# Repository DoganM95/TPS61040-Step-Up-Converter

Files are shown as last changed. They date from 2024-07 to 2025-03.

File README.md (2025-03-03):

# Intro

Step-Up converter module using TPS61040, ideal to boost a single li-ion cell (typically 2.5V - 4.2V) or a USB power supply (5V) to up to 28V, to power any device that does not need lots of current, but requires a very low quiescent current to ensure the battery is not drained, when there is no load.

## Specs of the IC

- 1.8V - 6V input
- 1.8V - 28V adj. output Voltage
- 0.4A output current
- 28uA quiescent current

## Specs of the PCB (measured)

- 2.2V - 6V input
- 2.2V - 28V adj. output
- 0.4A output
- 60 uA quiescent current

## Power Consumption 

Power consumed by the board alone with no load (quiescent current)

- 61 uA @ 6.0V in (6V out)
- 59 uA @ 5.0V in (6V out)
- 60 uA @ 4.2V in (6V out)
- 63 uA @ 3.3V in (6V out)
- 65 uA @ 3.0V in (6V out)
- 73 uA @ 2.2V in (6V out)

## Power Output

output range 2.93V - 13.87V  
output power @ 3.0V in  
V out without load -> V out with load after @  

- 13.87V loadless -> 13.8V @ 100mA  
- 12.00V loadless -> 11.8V @ 100 mA  
- 9.00V loadless -> 8.8V @ 100 mA  
- 6.0V loadless -> 5.8V @ 100mA  
- 5.0V loadless -> 4.7V @ 100mA  
- 3.3V loadless -> 3.0V @ 100mA  

## BOM

- `C_FF`: 0603 22pF
- `C_IN`: 0603 4.7uF
- `C_O`: 0603 1nF
- `D1`: any Schottky between SS14 & SS54
- `EN_J`: short, if board should be always on -> EN becomes redundant
- `L1`: CD43 10uH
- `R1`: 0603 up to 1MOhm, use if VR1 is unnecessary and needed resstance is known
- `R2`: 0603 100kOhm
- `U1`: SOT23-5 TPS61040
- `VR1`: 3x3 trimpot 1MOhm, sets output voltage by adjusting its resistance

## PCB

<table>
  <tr>
    <td>
      PCB Top View
    </td>
    <td>
      PCB Bottom View
    </td>
  </tr>
</table>

## Schematic



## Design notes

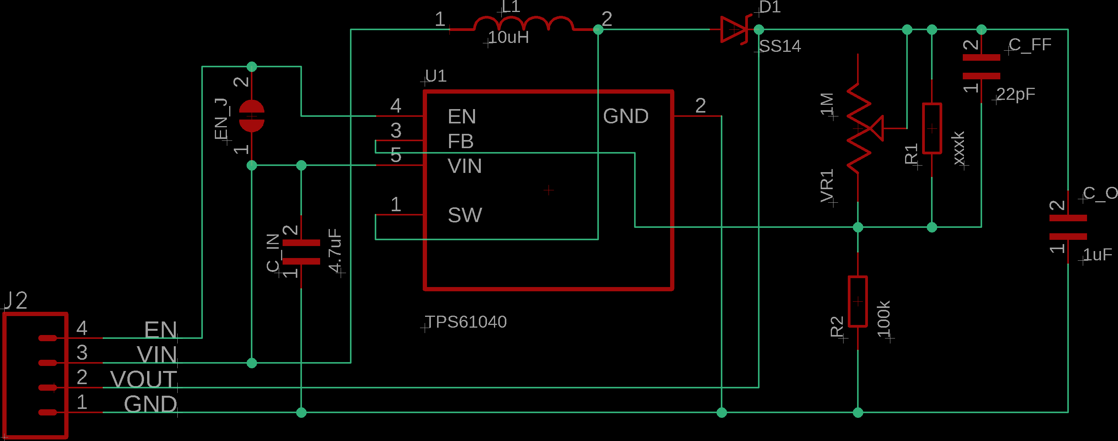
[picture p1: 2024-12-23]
assets/1.2_schematic.png

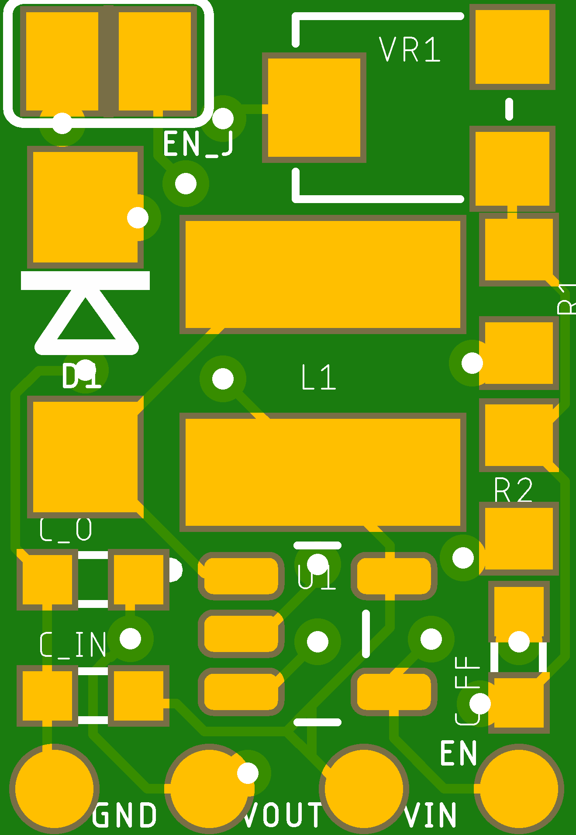
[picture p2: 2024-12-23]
assets/1.1-top.png

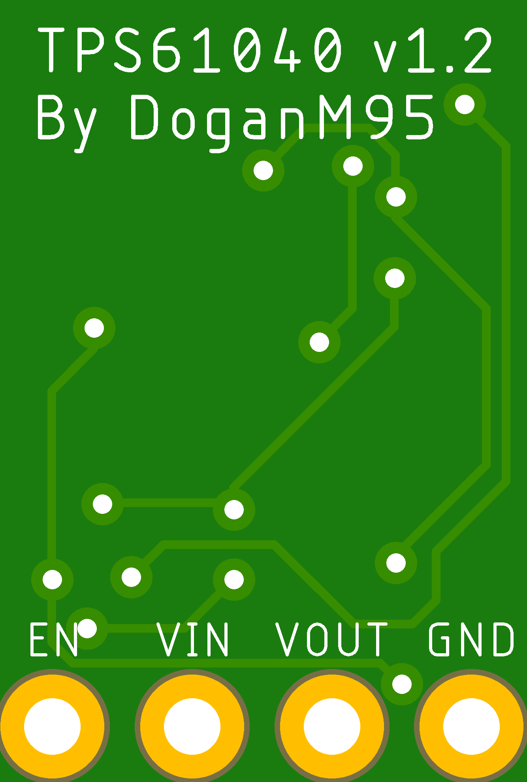
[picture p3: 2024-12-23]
assets/1.2-bottom.png

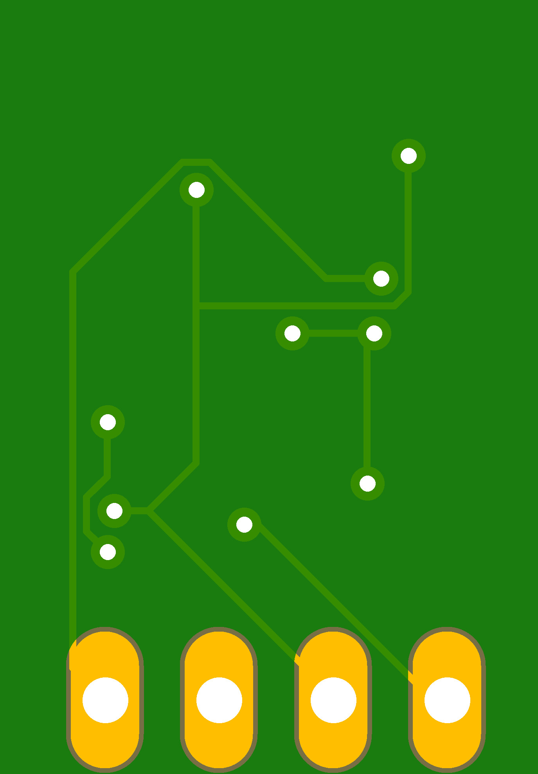
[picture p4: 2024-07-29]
assets/1.0-bottom.png

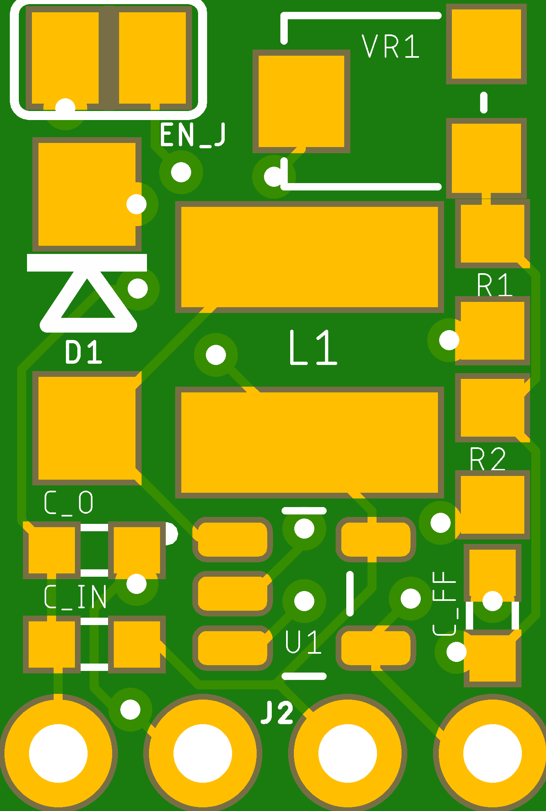
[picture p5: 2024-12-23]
assets/1.2-top.png

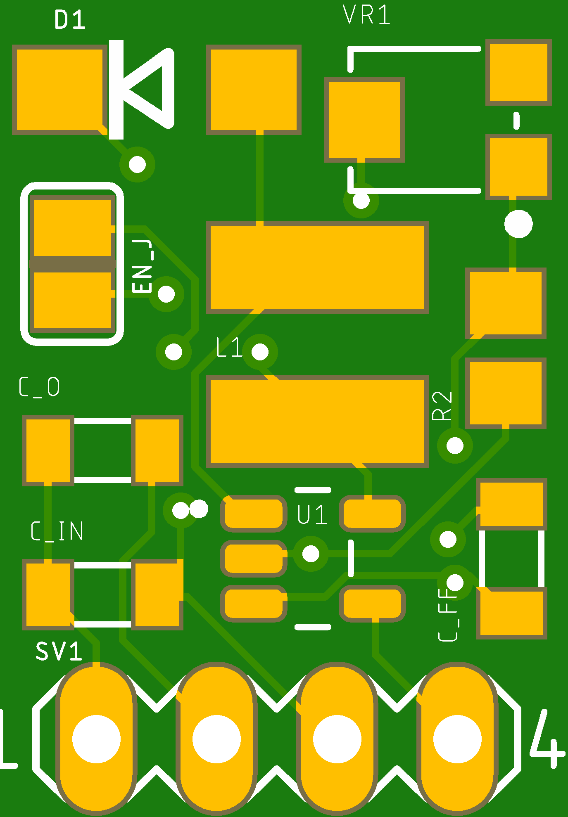
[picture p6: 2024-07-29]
assets/1.0-top.png

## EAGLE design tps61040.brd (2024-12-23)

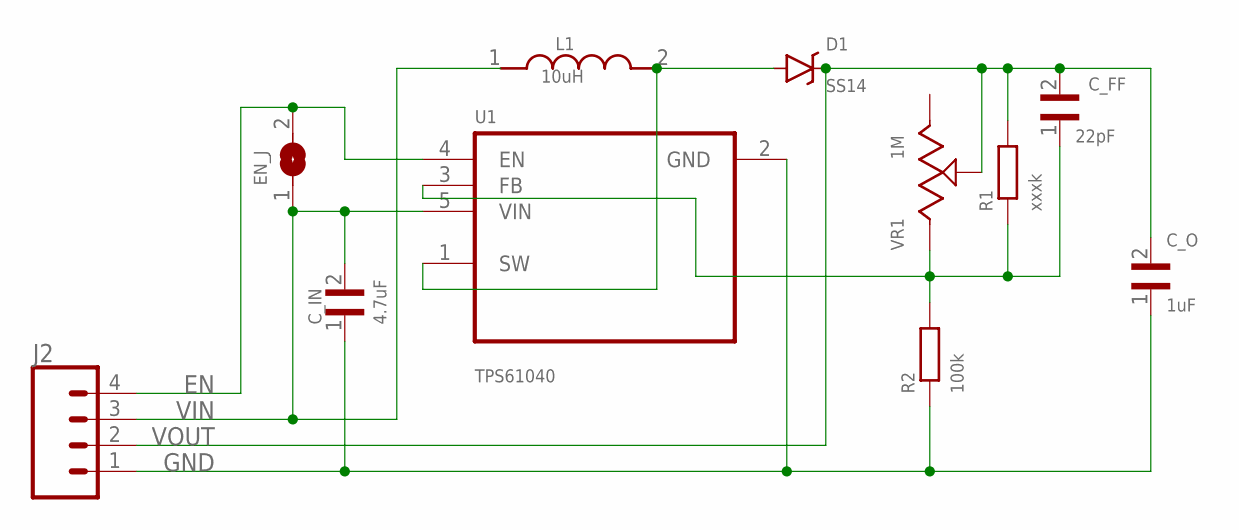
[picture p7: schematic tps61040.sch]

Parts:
C_FF: 22pF; WCAP-CSGP_0603_REFLOW
C_IN: 4.7uF; WCAP-CSGP_0603_REFLOW
C_O: 1uF; WCAP-CSGP_0603_REFLOW
D1: SS14; DO-214AC
EN_J: SJ
J2: CONN_041X04_NO_SILK; 1X04_NO_SILK
L1: 10uH; CD43
R1: xxxk; R0603
R2: 100k; R0603
U1: TPS61040; SOT95P280X145-5N
VR1: 1M; TRIMMER_TC33X-2-103G

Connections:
EN: EN_J.2, J2.4, U1.4 (EN)
GND: C_IN.1, C_O.1, J2.1, R2.1, U1.2 (GND)
unnamed: D1.A, L1.2, U1.1 (SW)
unnamed: C_FF.1, R1.1, R2.2, U1.3 (FB), VR1.1 (CCW)
VIN: C_IN.2, EN_J.1, J2.3, L1.1, U1.5 (VIN)
VOUT: C_FF.2, C_O.2, D1.C, J2.2, R1.2, VR1.2 (WIPER)

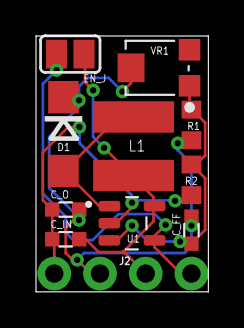
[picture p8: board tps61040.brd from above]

Board: 2 copper layers, 9.6 x 14.2 mm, 11 parts (0 on the bottom side), 6 nets.

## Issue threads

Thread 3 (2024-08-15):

Check quiescent current

DoganM95, 2024-08-15:
Draws to much current while doing nothing, as it drained 4 aaa batteries in a couple days. Check if this can be fixed or if the ic/datasheet is trash.

Closed 2024-12-23.

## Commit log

2024-07-14 add schematic
2024-07-14 add pcb images
2024-07-14 implement v1
    [tps61040.brd, tps61040.sch]
2024-07-14 switch to 0603 sized components
    [tps61040.brd, tps61040.sch]
2024-07-16 [ImgBot] Optimize images
    *Total -- 133.30kb -> 41.35kb (68.98%)
    /assets/pcb-bottom_v1.png -- 52.56kb -> 16.11kb (69.34%)
    /assets/pcb_v1.png -- 80.74kb -> 25.24kb (68.74%)
2024-07-29 update board to v1.1
    [tps61040.brd]
2024-07-29 update schematics to v1.1
    [tps61040.sch]
2024-07-29 add gerber of v1.1
2024-08-01 [ImgBot] Optimize images
    *Total -- 107.87kb -> 54.17kb (49.78%)
    /assets/pcb-bottom_v1.1.png -- 50.10kb -> 23.98kb (52.13%)
    /assets/pcb-top_v1.1.png -- 57.77kb -> 30.19kb (47.75%)
2024-12-23 Update qc with new resistors
2024-12-23 Create bom
2024-12-23 update to v1.2
    [tps61040.brd, tps61040.sch]
2024-12-23 create release (gerber file)
2024-12-23 add images of pcb v1.2 and schematic
2024-12-23 add space for header plastic
    [tps61040.brd]

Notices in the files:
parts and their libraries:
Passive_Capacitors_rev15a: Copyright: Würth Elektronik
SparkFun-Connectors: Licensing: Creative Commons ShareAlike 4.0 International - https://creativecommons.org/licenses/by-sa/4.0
